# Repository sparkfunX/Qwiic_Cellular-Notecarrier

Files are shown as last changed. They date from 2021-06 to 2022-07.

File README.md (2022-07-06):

SparkFun Qwiic Cellular Notecarrier - Blues Wireless
========================================

SparkX Qwiic Cellular Notecarrier (https://www.sparkfun.com/products/17114)

[*SparkX Qwiic Cellular Notecarrier (SPX-17114)*](https://www.sparkfun.com/products/17114)

When we first saw the Notecard from [Blues Wireless](https://blues.io/) we were intrigued. Unlike most embedded cellular modems, the price of the Blues Wireless card includes a 10 year subscription and 500MB of data. A global cellular module with a built in SIM card with no monthly fee? That sounds enticing. After all, the last thing we need is a hot water heater monitor with a monthly cell phone bill!

The power of Qwiic just keeps expanding! Simply plug the Qwiic Cellular Notecarrier onto any enabled SparkFun Qwiic platforms (currently [over 30](https://www.sparkfun.com/qwiic#products)) and you’ll be able to transmit data anywhere there is cell connectivity with a few lines of Python, Arduino, or JSON. The Blues documentation is superb. All [API calls](https://dev.blues.io/reference/notecard-api/) come with extensive C, Python, and JSON examples. While the Qwiic Cellular focuses on using the I2C bus for communication, USB and Serial can also be used to communicate with the Notecard. We found the USB was handy for immediate gratification and command debugging.

The Notecard module comes with integrated cellular, SIM, onboard GPS, accelerometer, and temperature sensor. The Qwiic Cellular product has everything you need: a carrier board (Blues calls them Notepads), the globally enabled [NB-IoT & LTE-M](https://shop.blues.io/products/note-nbgl-500) M.2 based module (Blues calls them Notecards), and two U.FL cables all assembled and ready to go.

Currently 139 countries are covered with another 33 countries covered by installing a user-supplied external SIM socket and card. See the [Covered Countries](https://dev.blues.io/hardware/notecard-datasheet/note-nbgl-500/#cellular-and-gps-gnss-antenna-requirements) table for more information. Two RF cables connect the Notecard to external SMA connectors for cellular and GPS antennas (sold separately in related items below).

SparkFun labored with love to create this code. Feel like supporting open source hardware? 
Buy a [board](https://www.sparkfun.com/products/17114) from SparkFun!

Repository Contents
-------------------

* **/hardware** - Eagle files

Documentation
--------------

* **[Quick Start Guide](https://dev.blues.io/get-started/quickstart/sparkfun-qwiic-cellular)**
* **[Installing an Arduino Library Guide](https://learn.sparkfun.com/tutorials/installing-an-arduino-library)** - Basic information on how to install an Arduino library.
* **[Notecard API](https://dev.blues.io/reference/notecard-api/introduction/)** - How to interface with Notecard from embedded processor applciations
* **[Notecard Datasheet](https://dev.blues.io/hardware/notecard-datasheet/note-nbgl-500/)** - Notecard datasheets
* **[Notecard Design Files](https://github.com/blues/note-hardware/tree/master/Notecard)** - Models and dimensioned drawings of Notecard

Products that use this Repository
--------------

* [SPX-17114](https://www.sparkfun.com/products/17114)

License Information
-------------------

This product is _**open source**_! 

Please review the LICENSE.md file for license information. 

If you have any questions or concerns on licensing, please contact technical support on our [SparkFun forums](https://forum.sparkfun.com/viewforum.php?f=152).

Distributed as-is; no warranty is given.

- Your friends at SparkFun.

_<COLLABORATION CREDIT>_

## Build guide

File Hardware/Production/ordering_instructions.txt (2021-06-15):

panel size, 152x155mm
PCB thickness, 1.6mm
number of layers, 2
soldermask color, Black
silkscreen color, White
oz copper, 1oz
finish, HASL lead free
stencils, none
pcs per panel, 6
min trace width, 0.1778mm / 0.0070in
min drill size, 0.3048mm / 0.0120in

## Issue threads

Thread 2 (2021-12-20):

Dimensions for notecarrier

gauteh, 2021-12-20:
Hi,

would you mind rendering a dimensions.pdf for the notecarrier?

Thank you, Gaute

nseidle, 2021-12-20:
[Qwiic-Cellular-Notepad Dimensional Drawing.pdf](https://github.com/sparkfunX/Qwiic_Cellular-Notecarrier/files/7748075/Qwiic-Cellular-Notepad.Dimensional.Drawing.pdf)

Let me know if I missed a critical dimension anywhere.

gauteh, 2021-12-21:
Thanks!

Gaute

man. 20. des. 2021, 22:40 skrev Nathan Seidle ***@***.***>:

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

Closed 2021-12-20.

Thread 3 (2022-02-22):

power: add supercaps + charger for GSM bursts (same as artemis AGT)

gauteh, 2022-02-22:
Hi,

I think it would make this board more versatile and robust if it had supercaps + charger in the same way as the artemis AGT. As it is now, it requires fairly specialized battery power. It seems that blues plan to rather suggest special batteries, than adding circuitry for handling the GSM bursts.

Regards, Gaute

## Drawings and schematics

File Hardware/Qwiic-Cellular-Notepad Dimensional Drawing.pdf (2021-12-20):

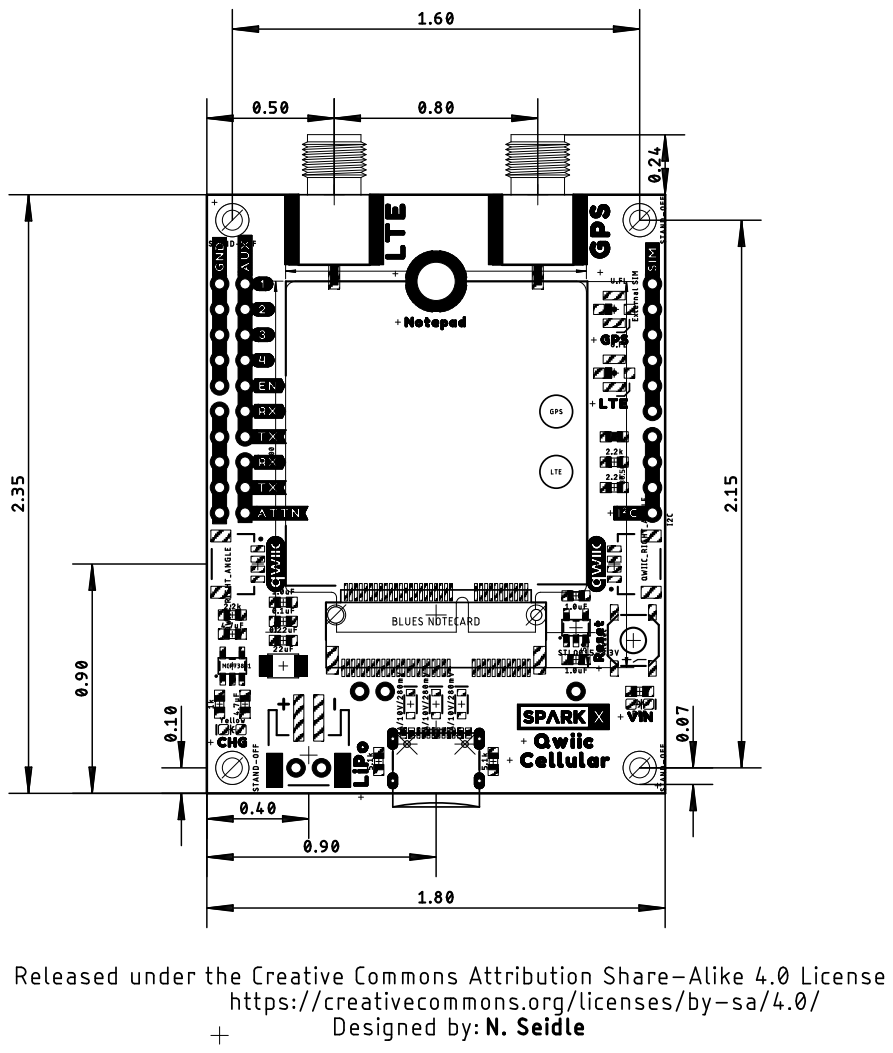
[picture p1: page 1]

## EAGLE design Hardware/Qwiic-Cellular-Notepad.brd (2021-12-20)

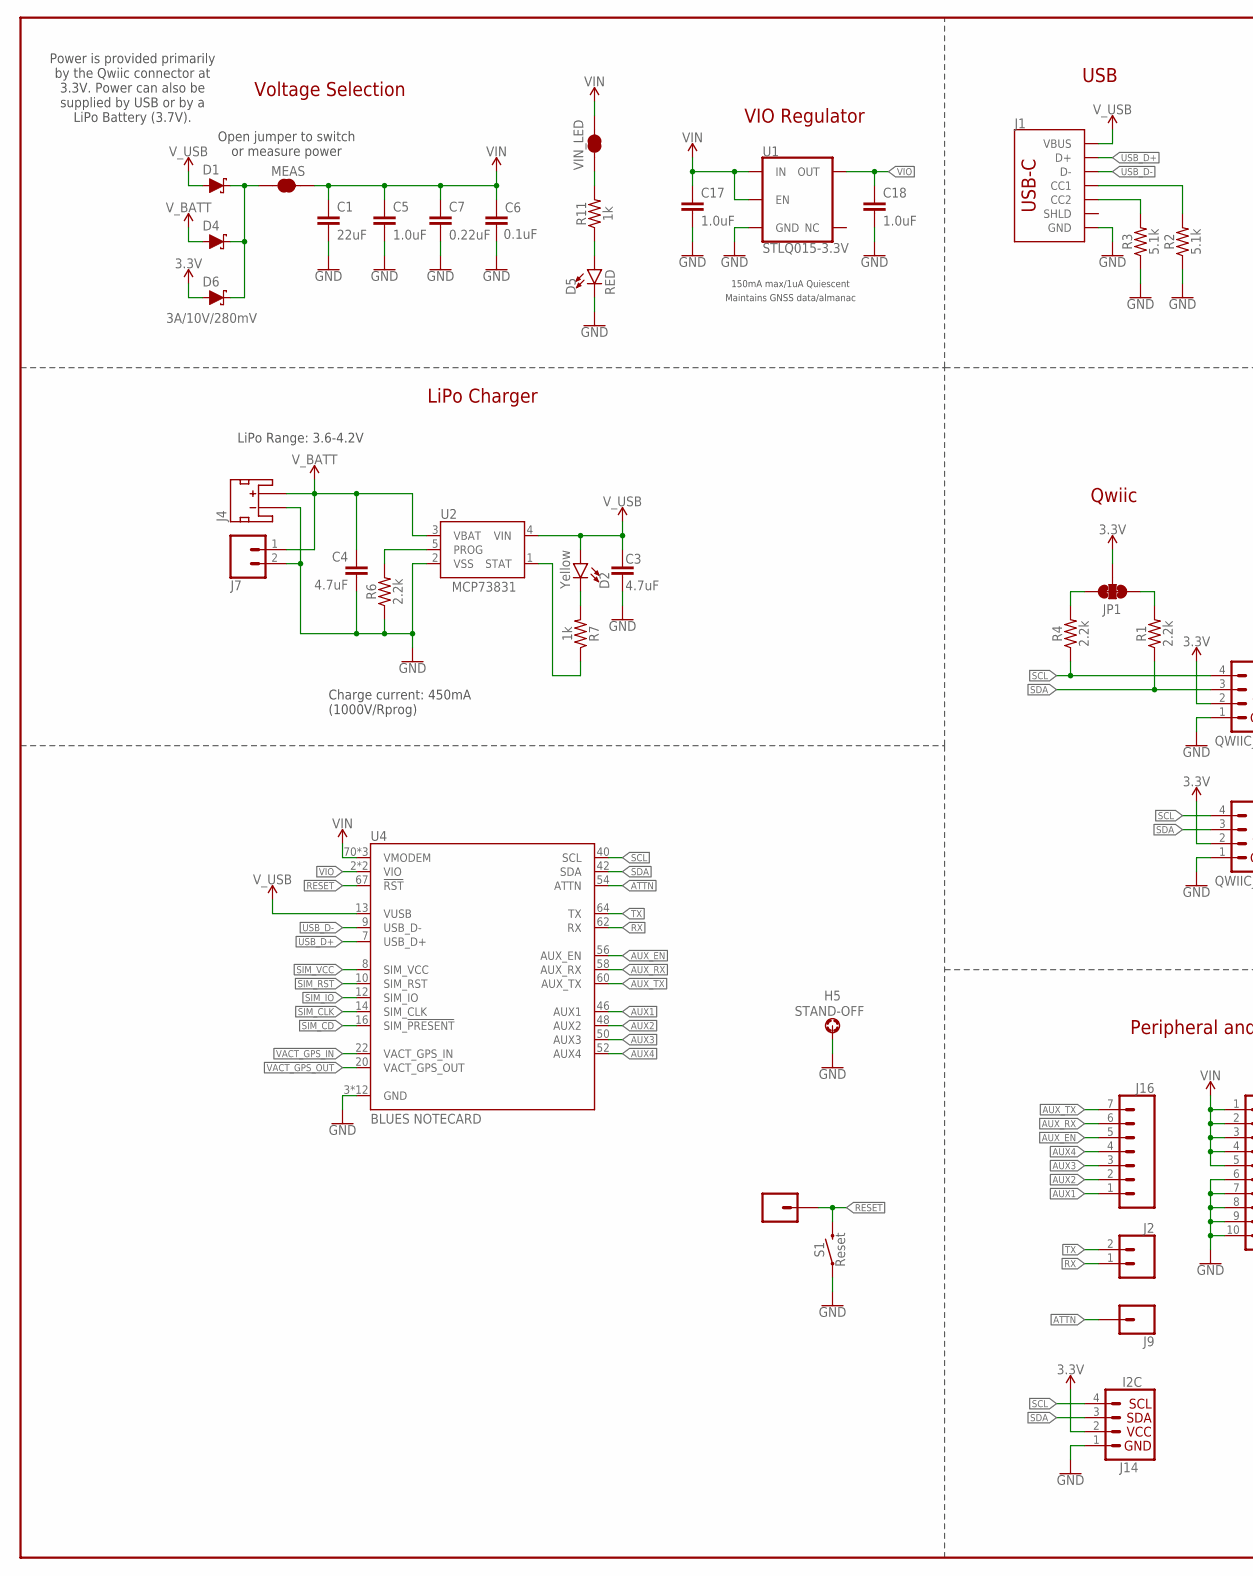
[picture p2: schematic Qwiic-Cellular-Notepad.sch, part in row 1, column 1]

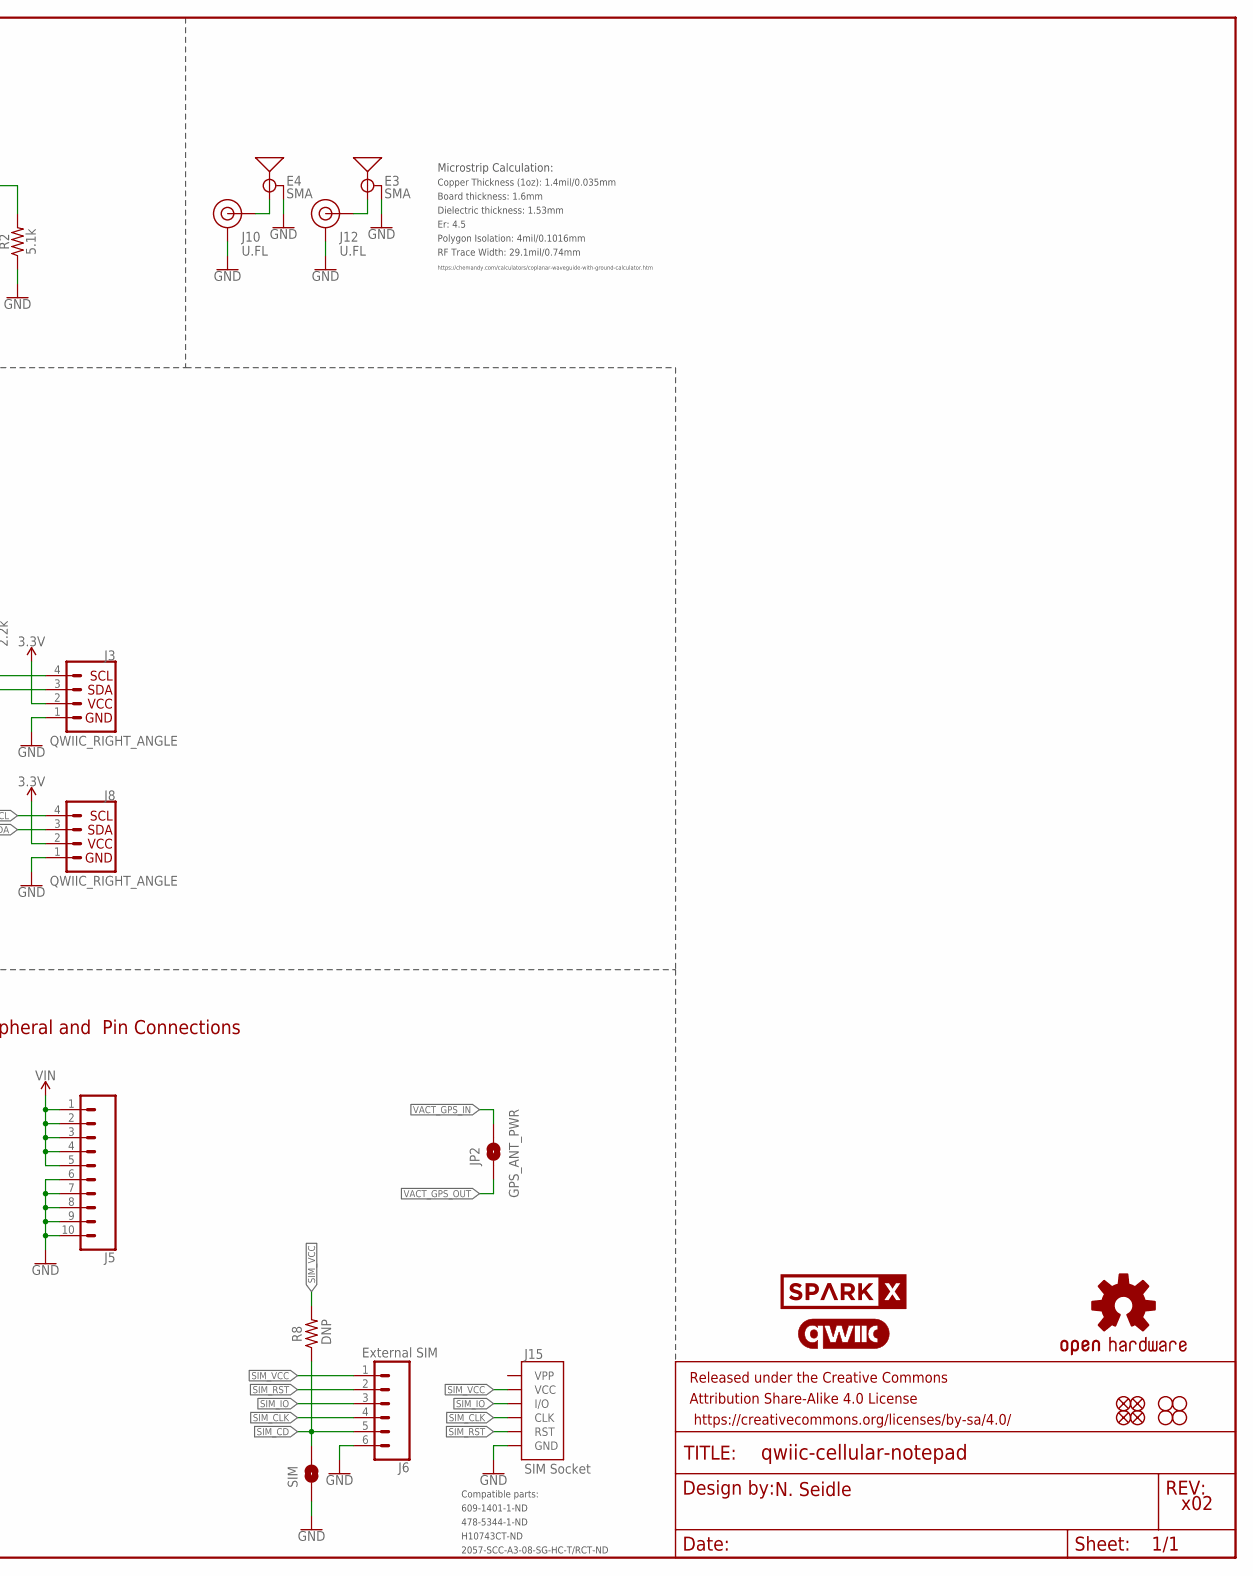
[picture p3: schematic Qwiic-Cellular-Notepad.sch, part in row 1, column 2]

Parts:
C1: 22uF; 1210
C3, C4: 4.7uF; 0603
C5, C17, C18: 1.0uF; 0603
C6: 0.1uF; 0603
C7: 0.22uF; 0603
D1, D4, D6: 3A/10V/280mV; SOD-323
D2: Yellow; LED-0603
D5: RED; LED-0603
E3, E4: SMA; SMA-EDGE-SMD
FD1, FD2, FD3, FD4: FIDUCIALUFIDUCIAL; FIDUCIAL-MICRO
FRAME1: FRAME-LEDGER; CREATIVE_COMMONS
H1, H2, H3, H4: STAND-OFF
H5: STAND-OFF; STAND-OFF-REFLOW-M2.5
J1: USB_C_2-LAYER_PADS; USB-C-16P-2LAYER-PADS
J2, J7: CONN_021X02_NO_SILK; 1X02_NO_SILK
J3, J8: QWIIC_RIGHT_ANGLE; JST04_1MM_RA
J4: JST_2MM_MALE; JST-2-SMD
J5: CONN_10NO_SILK_PTH_FEMALE; 1X10_NO_SILK
J6: External SIM; 1X06_NO_SILK
J9, J13: CONN_01PTH_NO_SILK_YES_STOP; 1X01_NO_SILK
J10, J12: U.FL
J14: I2C; 1X04_NO_SILK
J15: SIM Socket; SIMHOLDER
J16: CONN_07NO_SILK; 1X07_NO_SILK
JP1: JUMPER-SMT_3_2-NC_TRACE_SILK; SMT-JUMPER_3_2-NC_TRACE_SILK
JP2: GPS_ANT_PWR; SMT-JUMPER_2_NO_SILK
LOGO2: QWIIC_LOGO_CONNECTOR; QWIIC_5.5MM
LOGO3: OSHW-LOGOMINI; OSHW-LOGO-MINI
MEAS: JUMPER-COMBO_2_NC_TRACE; COMBO-JUMPER_2_NC_TRACE
R1, R4, R6: 2.2k; 0603
R2, R3: 5.1k; 0603
R7, R11: 1k; 0603
R8: DNP; 0603-RES
S1: Reset; TACTILE_SWITCH_SMD_5.2MM
SIM: JUMPER-SMT_2_NO_SILK; SMT-JUMPER_2_NO_SILK
U1: STLQ015-3.3V; SOT23-5
U2: MCP73831; SOT23-5
U4: BLUES NOTECARD; M.2-CONNECTOR-E
U$56: SPARKX-LOGO4; SPARKX-MEDIUM
VIN_LED: JUMPER-SMT_2_NC_TRACE_SILK; SMT-JUMPER_2_NC_TRACE_SILK

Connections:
3.3V: D6.A, J3.2, J8.2, J14.2, JP1.2
!RESET!: J13.1, S1.3 (2), S1.4 (2), U4.67 (!RST!)
ATTN: J9.1, U4.54 (ATTN)
AUX1: J16.1, U4.46 (AUX1)
AUX2: J16.2, U4.48 (AUX2)
AUX3: J16.3, U4.50 (AUX3)
AUX4: J16.4, U4.52 (AUX4)
AUX_EN: J16.5, U4.56 (AUX_EN)
AUX_RX: J16.6, U4.58 (AUX_RX)
AUX_TX: J16.7, U4.60 (AUX_TX)
CHG_LED: R7.1, U2.1 (STAT)
GND: C1.2, C3.2, C4.2, C5.2, C6.2, C7.2, C17.2, C18.2, D5.C, E3.GND@0 (GND), E3.GND@1 (GND), E4.GND@0 (GND), E4.GND@1 (GND), H5.1, J1.GND, J1.GND2 (GND), J3.1, J4.1 (-), J5.6, J5.7, J5.8, J5.9, J5.10, J6.6, J7.2, J8.1, J10.1 (GND), J10.2 (GND), J12.1 (GND), J12.2 (GND), J14.1, J15.C5 (GND), R2.1, R3.1, R6.1, S1.1, S1.2 (1), SIM.1, U1.2 (GND), U2.2 (VSS), U4.3 (GND), U4.5 (GND), U4.6 (GND), U4.11 (GND), U4.18 (GND), U4.33 (GND), U4.39 (GND), U4.45 (GND), U4.51 (GND), U4.57 (GND), U4.71 (GND), U4.73 (GND)
unnamed: JP1.3, R4.2
unnamed: JP1.1, R1.2
unnamed: D2.C, R7.2
unnamed: D5.A, R11.1
unnamed: R11.2, VIN_LED.1
unnamed: R6.2, U2.5 (PROG)
unnamed: J1.A5 (CC1), R2.2
unnamed: J1.B5 (CC2), R3.2
RF_GPS: E4.SIG (SIGNAL), J10.FEED (SIGNAL)
RF_LTE: E3.SIG (SIGNAL), J12.FEED (SIGNAL)
RX: J2.1, U4.62 (RX)
SCL: J3.4, J8.4, J14.4, R4.1, U4.40 (SCL)
SDA: J3.3, J8.3, J14.3, R1.1, U4.42 (SDA)
SIM_!CD!: J6.5, R8.1, SIM.2, U4.16 (SIM_!PRESENT!)
SIM_CLK: J6.4, J15.C3 (CLK), U4.14 (SIM_CLK)
SIM_IO: J6.3, J15.C7 (I/O), U4.12 (SIM_IO)
SIM_RST: J6.2, J15.C2 (RST), U4.10 (SIM_RST)
SIM_VCC: J6.1, J15.C1 (VCC), R8.2, U4.8 (SIM_VCC)
TX: J2.2, U4.64 (TX)
USB_D+: J1.A6 (D+), J1.B6 (D+), U4.7 (USB_D+)
USB_D-: J1.A7 (D-), J1.B7 (D-), U4.9 (USB_D-)
VACT_GPS_IN: JP2.2, U4.22 (VACT_GPS_IN)
VACT_GPS_OUT: JP2.1, U4.20 (VACT_GPS_OUT)
VIN: C1.1, C5.1, C6.1, C7.1, C17.1, J5.1, J5.2, J5.3, J5.4, J5.5, MEAS.2, MEAS.4 (2), U1.1 (IN), U1.3 (EN), U4.70 (VMODEM), U4.72 (VMODEM), U4.74 (VMODEM), VIN_LED.2
VIN1: D1.C, D4.C, D6.C, MEAS.1, MEAS.3 (1)
VIO: C18.1, U1.5 (OUT), U4.2 (VIO), U4.4 (VIO)
V_BATT: C4.1, D4.A, J4.2 (+), J7.1, U2.3 (VBAT)
V_USB: C3.1, D1.A, D2.A, J1.VBUS1 (VBUS), J1.VBUS2 (VBUS), U2.4 (VIN), U4.13 (VUSB)

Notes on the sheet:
USB
Peripheral and Pin Connections
Qwiic
Voltage Selection
LiPo Charger
LiPo Range: 3.6-4.2V
Charge current: 450mA (1000V/Rprog)
Open jumper to switch or measure power
N. Seidle
x02
Power is provided primarily by the Qwiic connector at 3.3V. Power can also be supplied by USB or by a LiPo Battery (3.7V).
Board thickness: 1.6mm
Er: 4.5
Copper Thickness (1oz): 1.4mil/0.035mm
RF Trace Width: 29.1mil/0.74mm
Polygon Isolation: 4mil/0.1016mm
Dielectric thickness: 1.53mm
https://chemandy.com/calculators/coplanar-waveguide-with-ground-calculator.htm
Microstrip Calculation:
Compatible parts:
609-1401-1-ND
478-5344-1-ND
H10743CT-ND
2057-SCC-A3-08-SG-HC-T/RCT-ND
VIO Regulator
150mA max/1uA Quiescent
Maintains GNSS data/almanac

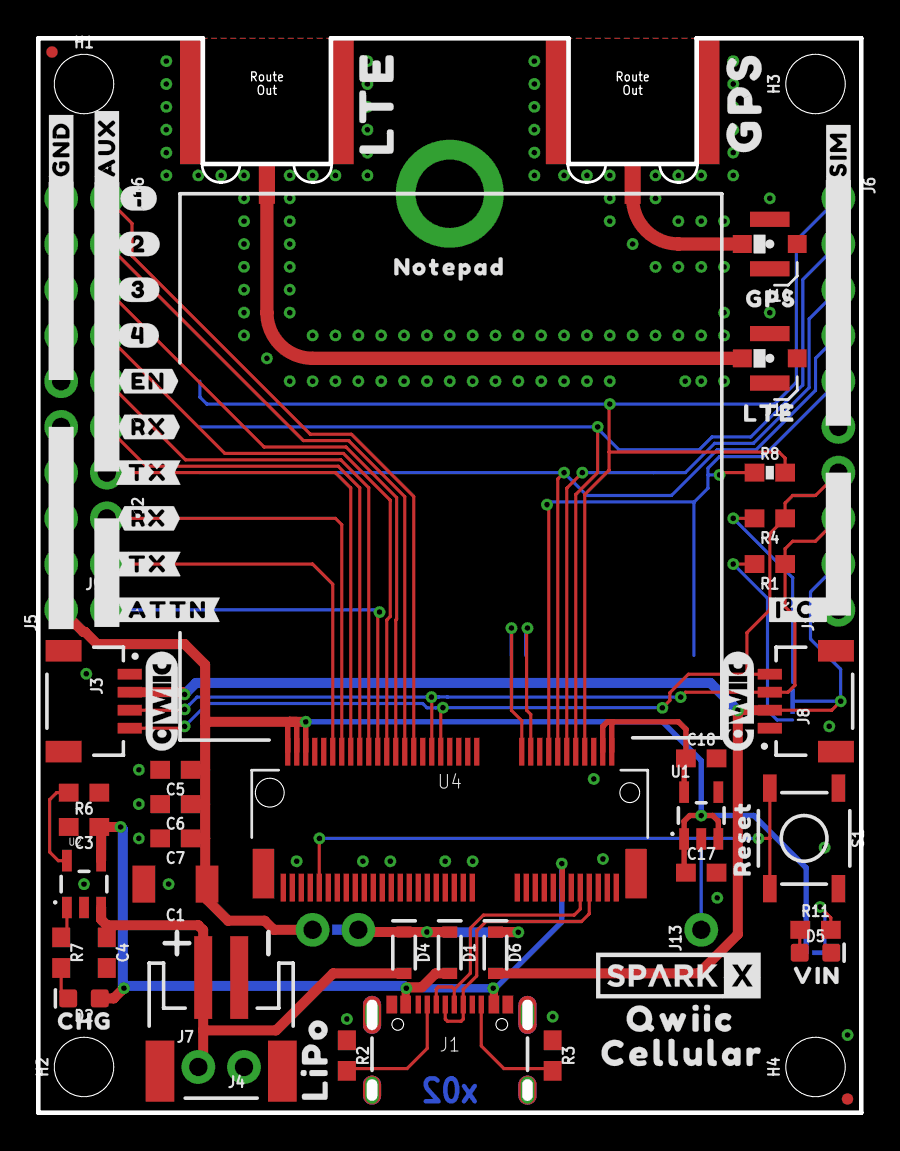
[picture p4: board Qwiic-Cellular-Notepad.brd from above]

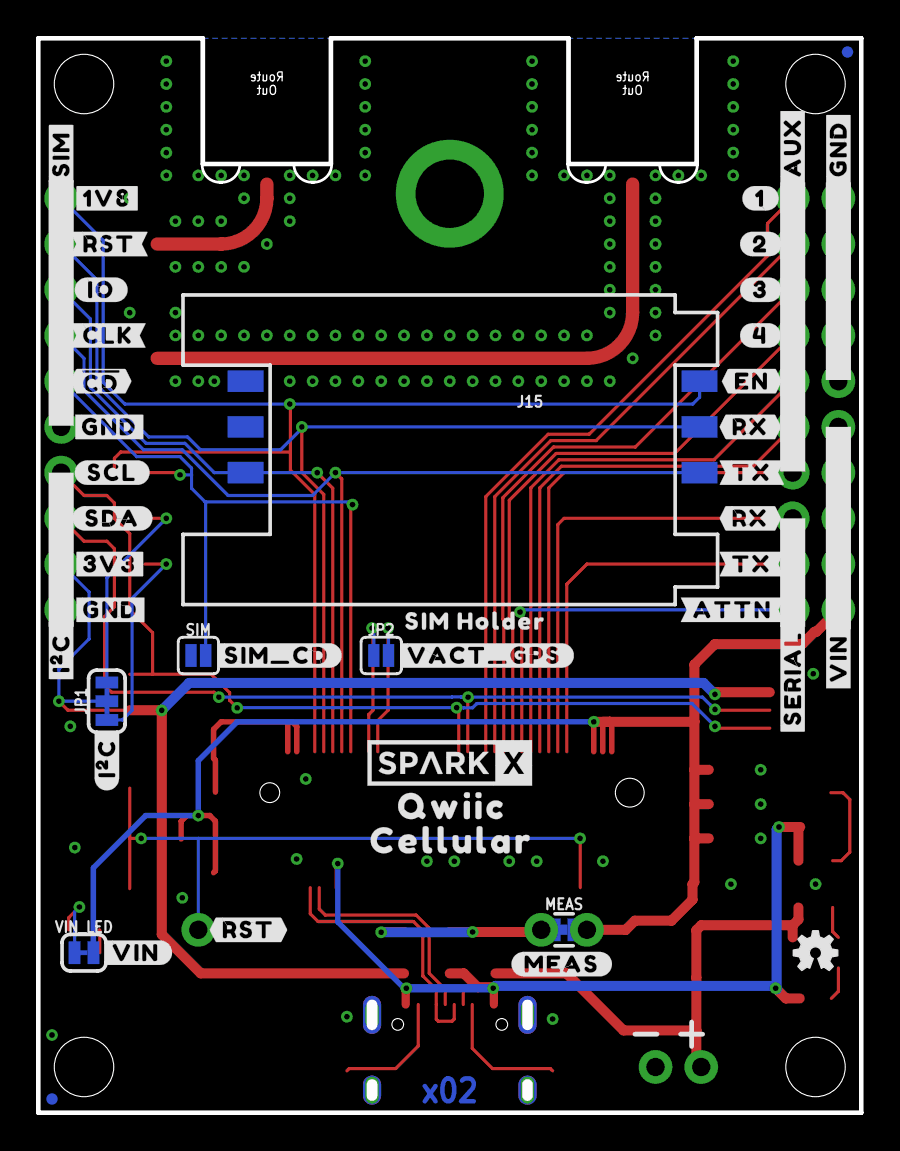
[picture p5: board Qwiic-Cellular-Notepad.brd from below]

Board: 2 copper layers, 45.7 x 59.7 mm, 122 parts (45 on the bottom side), 40 nets.

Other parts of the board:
LOGO5: QWIIC_LOGO_CONNECTOR; QWIIC_5.5MM
U$1, U$41: #1#1
U$2: #3V3#2
U$3, U$18, U$22: #GND#0
U$4, U$42: #2#2
U$5, U$43: #3#3
U$6, U$44: #4#4
U$7: GPS_0
U$8: #SERIAL#1
U$9, U$53: #I�C_#0
U$10: #I�C#0
U$11, U$40: #AUX#0
U$12: LTE_1
U$13: #GND#3
U$14, U$46: #RX#6
U$15: LIPO0
U$16, U$47: #TX#5
U$17: #SCL#1
U$19, U$45: #EN#0
U$20: NOTEPAD0
U$21: #SDA#0
U$23: #VIN#0
U$24: #VACT_GPS#0
U$25: #SIM_CD#0
U$26, U$31: QWIIC0
U$27: SIM_HOLDER0
U$28: #MEAS#3
U$29, U$32: CELLULAR1
U$30: #RST#0
U$33: #VIN#1
U$34: ##CD##1
U$35: #1V8#4
U$36: #CLK#3
U$37: #IO#2
U$38: #RST#5
U$39, U$51: #SIM#0
U$48, U$52: #RX#0
U$49, U$54: #TX#1
U$50, U$55: #ATTN#2
U$57: SPARKX-LOGO4; SPARKX-MEDIUM
U$58: GPS0
U$59: LTE1
U$92: RESET1
U$94: VIN1
U$96: CHG1

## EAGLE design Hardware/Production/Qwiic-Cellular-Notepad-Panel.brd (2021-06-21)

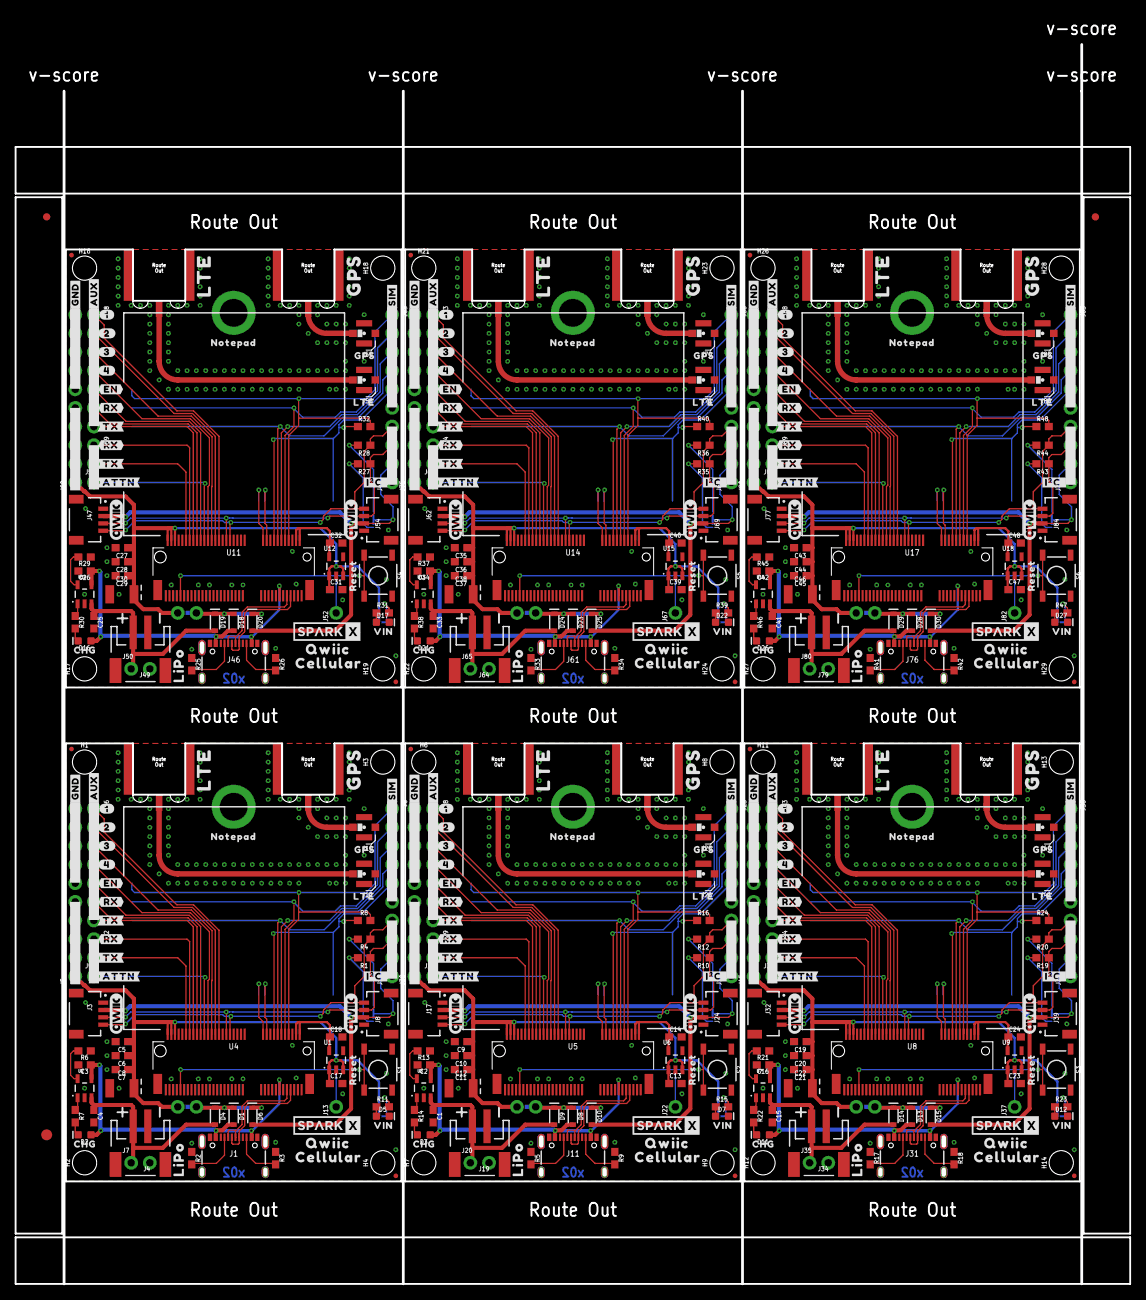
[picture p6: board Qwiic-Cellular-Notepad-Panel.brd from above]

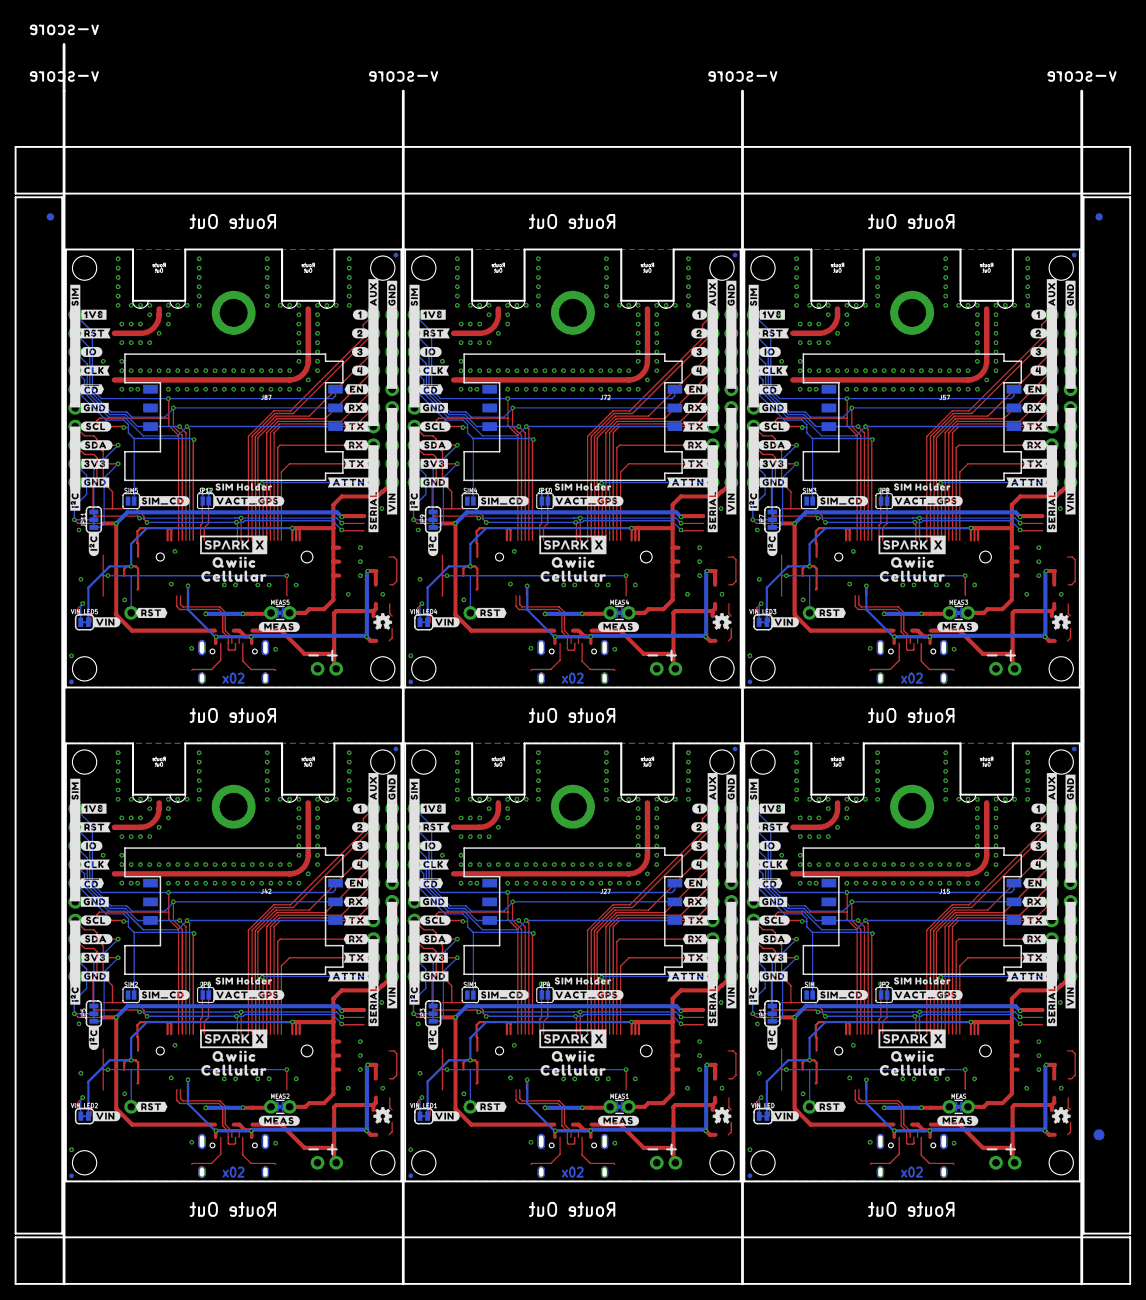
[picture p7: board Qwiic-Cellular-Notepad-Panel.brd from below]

Board: 2 copper layers, 151.9 x 168.9 mm, 732 parts (273 on the bottom side), 240 nets.

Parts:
C1, C2, C3, C4, C15, C16, C25, C26, C33, C34, C41, C42: 4.7uF; 0603
C5, C9, C13, C14, C17, C18, C19, C23, C24, C27, C31, C32, C35, C39, C40, C43, C47, C48: 1.0uF; 0603
C6, C10, C20, C28, C36, C44: 0.1uF; 0603
C7, C11, C21, C29, C37, C45: 0.22uF; 0603
C8, C12, C22, C30, C38, C46: 68uF; EIA3528
D1, D4, D6, D8, D9, D10, D13, D14, D15, D18, D19, D20, D23, D24, D25, D28, D29, D30: 3A/10V/280mV; SOD-323
D2, D3, D11, D16, D21, D26: Yellow; LED-0603
D5, D7, D12, D17, D22, D27: RED; LED-0603
E1, E2, E3, E4, E5, E6, E7, E8, E9, E10, E11, E12: SMA; SMA-EDGE-SMD
E$1, E$2, E$3, E$4: FIDUCIAL-1X2
E$5, E$6: FIDUCIAL-1.5X3
FD1, FD2, FD3, FD4, FD5, FD6, FD7, FD8, FD9, FD10, FD11, FD12, FD13, FD14, FD15, FD16, FD17, FD18, FD19, FD20, FD21, FD22, FD23, FD24: FIDUCIALUFIDUCIAL; FIDUCIAL-MICRO
H1, H2, H3, H4, H6, H7, H8, H9, H11, H12, H13, H14, H16, H17, H18, H19, H21, H22, H23, H24, H26, H27, H28, H29: STAND-OFF
H5, H10, H15, H20, H25, H30: STAND-OFF; STAND-OFF-REFLOW-M2.5
J1, J11, J31, J46, J61, J76: USB-C-16P-2LAYER-PADS
J2, J7, J20, J29, J35, J44, J50, J59, J65, J74, J80, J89: 1X02_NO_SILK
J3, J8, J17, J24, J32, J39, J47, J54, J62, J69, J77, J84: QWIIC_RIGHT_ANGLE; JST04_1MM_RA
J4, J19, J34, J49, J64, J79: JST-2-SMD
J5, J30, J45, J60, J75, J90: 1X10_NO_SILK
J6, J23, J38, J53, J68, J83: External SIM; 1X06_NO_SILK
J9, J13, J21, J22, J36, J37, J51, J52, J66, J67, J81, J82: 1X01_NO_SILK
J10, J12, J25, J26, J40, J41, J55, J56, J70, J71, J85, J86: U.FL
J14, J18, J33, J48, J63, J78: I2C; 1X04_NO_SILK
J15, J27, J42, J57, J72, J87: SIM Socket; SIMHOLDER
J16, J28, J43, J58, J73, J88: 1X07_NO_SILK
JP1, JP3, JP5, JP7, JP9, JP11: SMT-JUMPER_3_2-NC_TRACE_SILK
JP2, JP4, JP6, JP8, JP10, JP12: GPS_ANT_PWR; SMT-JUMPER_2_NO_SILK
LOGO1, LOGO2, LOGO5, LOGO6, LOGO7, LOGO9, LOGO10, LOGO12, LOGO13, LOGO15, LOGO16, LOGO18: QWIIC_LOGO_CONNECTOR; QWIIC_5.5MM
LOGO3, LOGO4, LOGO8, LOGO11, LOGO14, LOGO17: OSHW-LOGOMINI; OSHW-LOGO-MINI
MEAS, MEAS1, MEAS2, MEAS3, MEAS4, MEAS5: COMBO-JUMPER_2_NC_TRACE
R1, R4, R6, R10, R12, R13, R19, R20, R21, R27, R28, R29, R35, R36, R37, R43, R44, R45: 2.2k; 0603
R2, R3, R5, R9, R17, R18, R25, R26, R33, R34, R41, R42: 5.1k; 0603
R7, R11, R14, R15, R22, R23, R30, R31, R38, R39, R46, R47: 1k; 0603
R8, R16, R24, R32, R40, R48: 10k; 0603
S1, S2, S3, S4, S5, S6: Reset; TACTILE_SWITCH_SMD_5.2MM
SIM, SIM1, SIM2, SIM3, SIM4, SIM5: SMT-JUMPER_2_NO_SILK
U1, U6, U9, U12, U15, U18: STLQ015-3.3V; SOT23-5
U2, U3, U7, U10, U13, U16: MCP73831; SOT23-5
U4, U5, U8, U11, U14, U17: BLUES NOTECARD; M.2-CONNECTOR-E
U$1, U$41, U$83, U$111, U$148, U$173, U$210, U$235, U$272, U$297, U$334, U$359: #1#1
U$2, U$74, U$139, U$201, U$263, U$325: #3V3#2
U$3, U$18, U$22, U$63, U$73, U$109, U$128, U$138, U$171, U$190, U$200, U$233, U$252, U$262, U$295, U$314, U$324, U$357: #GND#0
U$4, U$42, U$84, U$112, U$149, U$174, U$211, U$236, U$273, U$298, U$335, U$360: #2#2
U$5, U$43, U$85, U$113, U$150, U$175, U$212, U$237, U$274, U$299, U$336, U$361: #3#3
U$6, U$44, U$86, U$114, U$151, U$176, U$213, U$238, U$275, U$300, U$337, U$362: #4#4
U$7, U$107, U$169, U$231, U$293, U$355: GPS_0
U$8, U$104, U$166, U$228, U$290, U$352: #SERIAL#1
U$9, U$53, U$106, U$122, U$168, U$184, U$230, U$246, U$292, U$308, U$354, U$370: #I�C_#0
U$10, U$105, U$167, U$229, U$291, U$353: #I�C#0
U$11, U$40, U$87, U$110, U$152, U$172, U$214, U$234, U$276, U$296, U$338, U$358: #AUX#0
U$12, U$108, U$170, U$232, U$294, U$356: LTE_1
U$13, U$75, U$140, U$202, U$264, U$326: #GND#3
U$14, U$46, U$88, U$116, U$153, U$178, U$215, U$240, U$277, U$302, U$339, U$364: #RX#6
U$15, U$64, U$129, U$191, U$253, U$315: LIPO0
U$16, U$47, U$89, U$117, U$154, U$179, U$216, U$241, U$278, U$303, U$340, U$365: #TX#5
U$17, U$76, U$141, U$203, U$265, U$327: #SCL#1
U$19, U$45, U$90, U$115, U$155, U$177, U$217, U$239, U$279, U$301, U$341, U$363: #EN#0
U$20, U$97, U$159, U$221, U$283, U$345: NOTEPAD0
U$21, U$77, U$142, U$204, U$266, U$328: #SDA#0
U$23, U$91, U$156, U$218, U$280, U$342: #VIN#0
U$24, U$78, U$143, U$205, U$267, U$329: #VACT_GPS#0
U$25, U$79, U$144, U$206, U$268, U$330: #SIM_CD#0
U$26, U$31, U$82, U$93, U$147, U$157, U$209, U$219, U$271, U$281, U$333, U$343: QWIIC0
U$27, U$80, U$145, U$207, U$269, U$331: SIM_HOLDER0
U$28, U$65, U$130, U$192, U$254, U$316: #MEAS#3
U$29, U$32, U$81, U$95, U$146, U$158, U$208, U$220, U$270, U$282, U$332, U$344: CELLULAR1
U$30, U$66, U$131, U$193, U$255, U$317: #RST#0
U$33, U$67, U$132, U$194, U$256, U$318: #VIN#1
U$34, U$99, U$161, U$223, U$285, U$347: ##CD##1
U$35, U$98, U$160, U$222, U$284, U$346: #1V8#4
U$36, U$100, U$162, U$224, U$286, U$348: #CLK#3
U$37, U$101, U$163, U$225, U$287, U$349: #IO#2
U$38, U$102, U$164, U$226, U$288, U$350: #RST#5
U$39, U$51, U$103, U$121, U$165, U$183, U$227, U$245, U$289, U$307, U$351, U$369: #SIM#0
U$48, U$52, U$68, U$118, U$133, U$180, U$195, U$242, U$257, U$304, U$319, U$366: #RX#0
U$49, U$54, U$69, U$119, U$134, U$181, U$196, U$243, U$258, U$305, U$320, U$367: #TX#1
U$50, U$55, U$70, U$120, U$135, U$182, U$197, U$244, U$259, U$306, U$321, U$368: #ATTN#2
U$56, U$57, U$123, U$124, U$185, U$186, U$247, U$248, U$309, U$310, U$371, U$372: SPARKX-LOGO4; SPARKX-MEDIUM
U$58, U$71, U$136, U$198, U$260, U$322: GPS0
U$59, U$72, U$137, U$199, U$261, U$323: LTE1
U$60, U$92, U$125, U$187, U$249, U$311: RESET1
U$61, U$94, U$126, U$188, U$250, U$312: VIN1
U$62, U$96, U$127, U$189, U$251, U$313: CHG1
VIN_LED, VIN_LED1, VIN_LED2, VIN_LED3, VIN_LED4, VIN_LED5: SMT-JUMPER_2_NC_TRACE_SILK

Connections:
3.3V: D6.A, J3.2, J8.2, J14.2, JP1.2
3.3V1: D10.A, J17.2, J18.2, J24.2, JP3.2
3.3V2: D15.A, J32.2, J33.2, J39.2, JP5.2
3.3V3: D20.A, J47.2, J48.2, J54.2, JP7.2
3.3V4: D25.A, J62.2, J63.2, J69.2, JP9.2
3.3V5: D30.A, J77.2, J78.2, J84.2, JP11.2
!RESET!: J13.1, S1.3, S1.4, U4.67
!RESET!1: J22.1, S2.3, S2.4, U5.67
!RESET!2: J37.1, S3.3, S3.4, U8.67
!RESET!3: J52.1, S4.3, S4.4, U11.67
!RESET!4: J67.1, S5.3, S5.4, U14.67
!RESET!5: J82.1, S6.3, S6.4, U17.67
ATTN: J9.1, U4.54
ATTN1: J21.1, U5.54
ATTN2: J36.1, U8.54
ATTN3: J51.1, U11.54
ATTN4: J66.1, U14.54
ATTN5: J81.1, U17.54
AUX1: J16.1, U4.46
AUX2: J16.2, U4.48
AUX3: J16.3, U4.50
AUX4: J16.4, U4.52
AUX5: J28.1, U5.46
AUX6: J28.2, U5.48
AUX7: J28.3, U5.50
AUX8: J28.4, U5.52
AUX9: J43.1, U8.46
AUX10: J43.2, U8.48
AUX11: J43.3, U8.50
AUX12: J43.4, U8.52
AUX13: J58.1, U11.46
AUX14: J58.2, U11.48
AUX15: J58.3, U11.50
AUX16: J58.4, U11.52
AUX17: J73.1, U14.46
AUX18: J73.2, U14.48
AUX19: J73.3, U14.50
AUX20: J73.4, U14.52
AUX21: J88.1, U17.46
AUX22: J88.2, U17.48
AUX23: J88.3, U17.50
AUX24: J88.4, U17.52
AUX_EN: J16.5, U4.56
AUX_EN1: J28.5, U5.56
AUX_EN2: J43.5, U8.56
AUX_EN3: J58.5, U11.56
AUX_EN4: J73.5, U14.56
AUX_EN5: J88.5, U17.56
AUX_RX: J16.6, U4.58
AUX_RX1: J28.6, U5.58
AUX_RX2: J43.6, U8.58
AUX_RX3: J58.6, U11.58
AUX_RX4: J73.6, U14.58
AUX_RX5: J88.6, U17.58
AUX_TX: J16.7, U4.60
AUX_TX1: J28.7, U5.60
AUX_TX2: J43.7, U8.60
AUX_TX3: J58.7, U11.60
AUX_TX4: J73.7, U14.60
AUX_TX5: J88.7, U17.60
CHG_LED: R7.1, U2.1
CHG_LED1: R14.1, U3.1
CHG_LED2: R22.1, U7.1
CHG_LED3: R30.1, U10.1
CHG_LED4: R38.1, U13.1
CHG_LED5: R46.1, U16.1
GND: C3.2, C4.2, C5.2, C6.2, C7.2, C8.C, C17.2, C18.2, D5.C, E3.GND@0, E3.GND@1, E4.GND@0, E4.GND@1, H5.1, J1.GND, J1.GND2, J3.1, J4.1, J5.6, J5.7, J5.8, J5.9, J5.10, J6.6, J7.2, J8.1, J10.1, J10.2, J12.1, J12.2, J14.1, J15.C5, R2.1, R3.1, R6.1, S1.1, S1.2, SIM.1, U1.2, U2.2, U4.3, U4.5, U4.6, U4.11, U4.18, U4.33, U4.39, U4.45, U4.51, U4.57, U4.71, U4.73
GND1: C1.2, C2.2, C9.2, C10.2, C11.2, C12.C, C13.2, C14.2, D7.C, E1.GND@0, E1.GND@1, E2.GND@0, E2.GND@1, H10.1, J11.GND, J11.GND2, J17.1, J18.1, J19.1, J20.2, J23.6, J24.1, J25.1, J25.2, J26.1, J26.2, J27.C5, J30.6, J30.7, J30.8, J30.9, J30.10, R5.1, R9.1, R13.1, S2.1, S2.2, SIM1.1, U3.2, U5.3, U5.5, U5.6, U5.11, U5.18, U5.33, U5.39, U5.45, U5.51, U5.57, U5.71, U5.73, U6.2
GND2: C15.2, C16.2, C19.2, C20.2, C21.2, C22.C, C23.2, C24.2, D12.C, E5.GND@0, E5.GND@1, E6.GND@0, E6.GND@1, H15.1, J31.GND, J31.GND2, J32.1, J33.1, J34.1, J35.2, J38.6, J39.1, J40.1, J40.2, J41.1, J41.2, J42.C5, J45.6, J45.7, J45.8, J45.9, J45.10, R17.1, R18.1, R21.1, S3.1, S3.2, SIM2.1, U7.2, U8.3, U8.5, U8.6, U8.11, U8.18, U8.33, U8.39, U8.45, U8.51, U8.57, U8.71, U8.73, U9.2
GND3: C25.2, C26.2, C27.2, C28.2, C29.2, C30.C, C31.2, C32.2, D17.C, E7.GND@0, E7.GND@1, E8.GND@0, E8.GND@1, H20.1, J46.GND, J46.GND2, J47.1, J48.1, J49.1, J50.2, J53.6, J54.1, J55.1, J55.2, J56.1, J56.2, J57.C5, J60.6, J60.7, J60.8, J60.9, J60.10, R25.1, R26.1, R29.1, S4.1, S4.2, SIM3.1, U10.2, U11.3, U11.5, U11.6, U11.11, U11.18, U11.33, U11.39, U11.45, U11.51, U11.57, U11.71, U11.73, U12.2
GND4: C33.2, C34.2, C35.2, C36.2, C37.2, C38.C, C39.2, C40.2, D22.C, E9.GND@0, E9.GND@1, E10.GND@0, E10.GND@1, H25.1, J61.GND, J61.GND2, J62.1, J63.1, J64.1, J65.2, J68.6, J69.1, J70.1, J70.2, J71.1, J71.2, J72.C5, J75.6, J75.7, J75.8, J75.9, J75.10, R33.1, R34.1, R37.1, S5.1, S5.2, SIM4.1, U13.2, U14.3, U14.5, U14.6, U14.11, U14.18, U14.33, U14.39, U14.45, U14.51, U14.57, U14.71, U14.73, U15.2
GND5: C41.2, C42.2, C43.2, C44.2, C45.2, C46.C, C47.2, C48.2, D27.C, E11.GND@0, E11.GND@1, E12.GND@0, E12.GND@1, H30.1, J76.GND, J76.GND2, J77.1, J78.1, J79.1, J80.2, J83.6, J84.1, J85.1, J85.2, J86.1, J86.2, J87.C5, J90.6, J90.7, J90.8, J90.9, J90.10, R41.1, R42.1, R45.1, S6.1, S6.2, SIM5.1, U16.2, U17.3, U17.5, U17.6, U17.11, U17.18, U17.33, U17.39, U17.45, U17.51, U17.57, U17.71, U17.73, U18.2
unnamed: J11.A5, R5.2
unnamed: JP1.3, R4.2
unnamed: JP1.1, R1.2
unnamed: D2.C, R7.2
unnamed: D5.A, R11.1
unnamed: R11.2, VIN_LED.1
unnamed: R6.2, U2.5
unnamed: J11.B5, R9.2
unnamed: JP3.3, R12.2
unnamed: J1.A5, R2.2
unnamed: J1.B5, R3.2
unnamed: JP3.1, R10.2
unnamed: R13.2, U3.5
unnamed: D3.C, R14.2
unnamed: R15.2, VIN_LED1.1
unnamed: D7.A, R15.1
unnamed: J31.A5, R17.2
unnamed: J31.B5, R18.2
unnamed: JP5.3, R20.2
unnamed: JP5.1, R19.2
unnamed: R21.2, U7.5
unnamed: D11.C, R22.2
unnamed: R23.2, VIN_LED2.1
unnamed: D12.A, R23.1
unnamed: J46.A5, R25.2
unnamed: J46.B5, R26.2
unnamed: JP7.3, R28.2
unnamed: JP7.1, R27.2
unnamed: R29.2, U10.5
unnamed: D16.C, R30.2
unnamed: R31.2, VIN_LED3.1
unnamed: D17.A, R31.1
unnamed: J61.A5, R33.2
unnamed: J61.B5, R34.2
unnamed: JP9.3, R36.2
unnamed: JP9.1, R35.2
unnamed: R37.2, U13.5
unnamed: D21.C, R38.2
unnamed: R39.2, VIN_LED4.1
unnamed: D22.A, R39.1
unnamed: J76.A5, R41.2
unnamed: J76.B5, R42.2
unnamed: JP11.3, R44.2
unnamed: JP11.1, R43.2
unnamed: R45.2, U16.5
unnamed: D26.C, R46.2
unnamed: R47.2, VIN_LED5.1
unnamed: D27.A, R47.1
RF_GPS: E4.SIG, J10.FEED
RF_GPS1: E2.SIG, J25.FEED
RF_GPS2: E6.SIG, J40.FEED
RF_GPS3: E8.SIG, J55.FEED
RF_GPS4: E10.SIG, J70.FEED
RF_GPS5: E12.SIG, J85.FEED
RF_LTE: E3.SIG, J12.FEED
RF_LTE1: E1.SIG, J26.FEED
RF_LTE2: E5.SIG, J41.FEED
RF_LTE3: E7.SIG, J56.FEED
RF_LTE4: E9.SIG, J71.FEED
RF_LTE5: E11.SIG, J86.FEED
RX: J2.1, U4.62
RX1: J29.1, U5.62
RX2: J44.1, U8.62
RX3: J59.1, U11.62
RX4: J74.1, U14.62
RX5: J89.1, U17.62
SCL: J3.4, J8.4, J14.4, R4.1, U4.40
SCL1: J17.4, J18.4, J24.4, R12.1, U5.40
SCL2: J32.4, J33.4, J39.4, R20.1, U8.40
SCL3: J47.4, J48.4, J54.4, R28.1, U11.40
SCL4: J62.4, J63.4, J69.4, R36.1, U14.40
SCL5: J77.4, J78.4, J84.4, R44.1, U17.40
SDA: J3.3, J8.3, J14.3, R1.1, U4.42
SDA1: J17.3, J18.3, J24.3, R10.1, U5.42
SDA2: J32.3, J33.3, J39.3, R19.1, U8.42
SDA3: J47.3, J48.3, J54.3, R27.1, U11.42
SDA4: J62.3, J63.3, J69.3, R35.1, U14.42
SDA5: J77.3, J78.3, J84.3, R43.1, U17.42
SIM_!CD!: J6.5, R8.1, SIM.2, U4.16
SIM_!CD!1: J23.5, R16.1, SIM1.2, U5.16
SIM_!CD!2: J38.5, R24.1, SIM2.2, U8.16
SIM_!CD!3: J53.5, R32.1, SIM3.2, U11.16
SIM_!CD!4: J68.5, R40.1, SIM4.2, U14.16
SIM_!CD!5: J83.5, R48.1, SIM5.2, U17.16
SIM_CLK: J6.4, J15.C3, U4.14
SIM_CLK1: J23.4, J27.C3, U5.14
SIM_CLK2: J38.4, J42.C3, U8.14
SIM_CLK3: J53.4, J57.C3, U11.14
SIM_CLK4: J68.4, J72.C3, U14.14
SIM_CLK5: J83.4, J87.C3, U17.14
SIM_IO: J6.3, J15.C7, U4.12
SIM_IO1: J23.3, J27.C7, U5.12
SIM_IO2: J38.3, J42.C7, U8.12
SIM_IO3: J53.3, J57.C7, U11.12
SIM_IO4: J68.3, J72.C7, U14.12
SIM_IO5: J83.3, J87.C7, U17.12
SIM_RST: J6.2, J15.C2, U4.10
SIM_RST1: J23.2, J27.C2, U5.10
SIM_RST2: J38.2, J42.C2, U8.10
SIM_RST3: J53.2, J57.C2, U11.10
SIM_RST4: J68.2, J72.C2, U14.10
SIM_RST5: J83.2, J87.C2, U17.10
SIM_VCC: J6.1, J15.C1, R8.2, U4.8
SIM_VCC1: J23.1, J27.C1, R16.2, U5.8
SIM_VCC2: J38.1, J42.C1, R24.2, U8.8
SIM_VCC3: J53.1, J57.C1, R32.2, U11.8
SIM_VCC4: J68.1, J72.C1, R40.2, U14.8
SIM_VCC5: J83.1, J87.C1, R48.2, U17.8
TX: J2.2, U4.64
TX1: J29.2, U5.64
TX2: J44.2, U8.64
TX3: J59.2, U11.64
TX4: J74.2, U14.64
TX5: J89.2, U17.64
USB_D+: J1.A6, J1.B6, U4.7
USB_D+1: J11.A6, J11.B6, U5.7
USB_D+2: J31.A6, J31.B6, U8.7
USB_D+3: J46.A6, J46.B6, U11.7
USB_D+4: J61.A6, J61.B6, U14.7
USB_D+5: J76.A6, J76.B6, U17.7
USB_D-: J1.A7, J1.B7, U4.9
USB_D-1: J11.A7, J11.B7, U5.9
USB_D-2: J31.A7, J31.B7, U8.9
USB_D-3: J46.A7, J46.B7, U11.9
USB_D-4: J61.A7, J61.B7, U14.9
USB_D-5: J76.A7, J76.B7, U17.9
VACT_GPS_IN: JP2.2, U4.22
VACT_GPS_IN1: JP4.2, U5.22
VACT_GPS_IN2: JP6.2, U8.22
VACT_GPS_IN3: JP8.2, U11.22
VACT_GPS_IN4: JP10.2, U14.22
VACT_GPS_IN5: JP12.2, U17.22
VACT_GPS_OUT: JP2.1, U4.20
VACT_GPS_OUT1: JP4.1, U5.20
VACT_GPS_OUT2: JP6.1, U8.20
VACT_GPS_OUT3: JP8.1, U11.20
VACT_GPS_OUT4: JP10.1, U14.20
VACT_GPS_OUT5: JP12.1, U17.20
VIN: C5.1, C6.1, C7.1, C8.A, C17.1, J5.1, J5.2, J5.3, J5.4, J5.5, MEAS.2, MEAS.4, U1.1, U1.3, U4.70, U4.72, U4.74, VIN_LED.2
VIN1: D1.C, D4.C, D6.C, MEAS.1, MEAS.3
VIN2: C9.1, C10.1, C11.1, C12.A, C13.1, J30.1, J30.2, J30.3, J30.4, J30.5, MEAS1.2, MEAS1.4, U5.70, U5.72, U5.74, U6.1, U6.3, VIN_LED1.2
VIN3: D8.C, D9.C, D10.C, MEAS1.1, MEAS1.3
VIN4: C19.1, C20.1, C21.1, C22.A, C23.1, J45.1, J45.2, J45.3, J45.4, J45.5, MEAS2.2, MEAS2.4, U8.70, U8.72, U8.74, U9.1, U9.3, VIN_LED2.2
VIN5: D13.C, D14.C, D15.C, MEAS2.1, MEAS2.3
VIN6: C27.1, C28.1, C29.1, C30.A, C31.1, J60.1, J60.2, J60.3, J60.4, J60.5, MEAS3.2, MEAS3.4, U11.70, U11.72, U11.74, U12.1, U12.3, VIN_LED3.2
VIN7: D18.C, D19.C, D20.C, MEAS3.1, MEAS3.3
VIN8: C35.1, C36.1, C37.1, C38.A, C39.1, J75.1, J75.2, J75.3, J75.4, J75.5, MEAS4.2, MEAS4.4, U14.70, U14.72, U14.74, U15.1, U15.3, VIN_LED4.2
VIN9: D23.C, D24.C, D25.C, MEAS4.1, MEAS4.3
VIN10: C43.1, C44.1, C45.1, C46.A, C47.1, J90.1, J90.2, J90.3, J90.4, J90.5, MEAS5.2, MEAS5.4, U17.70, U17.72, U17.74, U18.1, U18.3, VIN_LED5.2
VIN11: D28.C, D29.C, D30.C, MEAS5.1, MEAS5.3
VIO: C18.1, U1.5, U4.2, U4.4
VIO1: C14.1, U5.2, U5.4, U6.5
VIO2: C24.1, U8.2, U8.4, U9.5
VIO3: C32.1, U11.2, U11.4, U12.5
VIO4: C40.1, U14.2, U14.4, U15.5
VIO5: C48.1, U17.2, U17.4, U18.5
V_BATT: C4.1, D4.A, J4.2, J7.1, U2.3
V_BATT1: C1.1, D9.A, J19.2, J20.1, U3.3
V_BATT2: C15.1, D14.A, J34.2, J35.1, U7.3
V_BATT3: C25.1, D19.A, J49.2, J50.1, U10.3
V_BATT4: C33.1, D24.A, J64.2, J65.1, U13.3
V_BATT5: C41.1, D29.A, J79.2, J80.1, U16.3
V_USB: C3.1, D1.A, D2.A, J1.VBUS1, J1.VBUS2, U2.4, U4.13
V_USB1: C2.1, D3.A, D8.A, J11.VBUS1, J11.VBUS2, U3.4, U5.13
V_USB2: C16.1, D11.A, D13.A, J31.VBUS1, J31.VBUS2, U7.4, U8.13
V_USB3: C26.1, D16.A, D18.A, J46.VBUS1, J46.VBUS2, U10.4, U11.13
V_USB4: C34.1, D21.A, D23.A, J61.VBUS1, J61.VBUS2, U13.4, U14.13
V_USB5: C42.1, D26.A, D28.A, J76.VBUS1, J76.VBUS2, U16.4, U17.13

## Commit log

2021-06-15 Fix Notecard FP. Add VIO vreg. x02 release.
    [Qwiic-Cellular-Notepad-Panel.GBL, Qwiic-Cellular-Notepad-Panel.GBO, Qwiic-Cellular-Notepad-Panel.GBS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]
2021-06-21 Change to 22uF cap. Add production files.
    [Qwiic-Cellular-Notepad-Panel.GBL, Qwiic-Cellular-Notepad-Panel.GBO, Qwiic-Cellular-Notepad-Panel.GBP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]
2021-06-21 Add production files.
    [Qwiic-Cellular-Notepad-Panel.GBL, Qwiic-Cellular-Notepad-Panel.GBO, Qwiic-Cellular-Notepad-Panel.GBP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]
2021-08-29 Change R8 to DNP.
    [Qwiic-Cellular-Notepad.brd, Qwiic-Cellular-Notepad.sch]
2021-12-20 Add dimensionals
    [Qwiic-Cellular-Notepad.brd]

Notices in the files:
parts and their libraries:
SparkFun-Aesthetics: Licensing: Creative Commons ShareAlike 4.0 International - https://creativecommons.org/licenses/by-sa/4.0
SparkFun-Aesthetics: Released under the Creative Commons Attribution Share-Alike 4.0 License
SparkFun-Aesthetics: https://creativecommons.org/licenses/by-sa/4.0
